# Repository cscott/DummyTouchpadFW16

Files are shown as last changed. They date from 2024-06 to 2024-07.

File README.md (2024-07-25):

# Dummy Touchpad Input Module
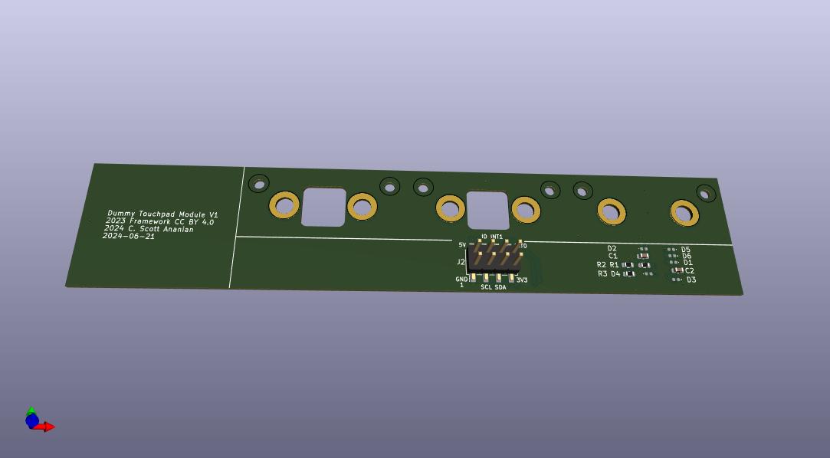
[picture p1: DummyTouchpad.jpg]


This is a dummy touchpad.  All it does is contain the resistors and pads to
tell the FW16 that there is a touchpad installed (though there is not).
It also brings the signal lines out to a 2.54mm SMT header, but that's
mostly for debugging/development, not for any real use.

If you are using this in conjunction with a
[full width touchpad spacer](https://github.com/cscott/TouchpadSpacerFW16)
don't populate the header.

Here's the [schematic](./MinimalSmallInputModule.pdf).

## License
Input Modules © 2023 by Framework Computer Inc is licensed under CC BY 4.0. To view a copy of this license, visit http://creativecommons.org/licenses/by/4.0/

## Fabrication and Assembly
Use a 0.8mm PCB for Input Modules.

As with the Framework [example](https://github.com/FrameworkComputer/InputModules/tree/main/Electrical/MicrocontrollerInputModule) use Keystone 24929
"zero height threaded inserts" ([available from Digikey](https://www.digikey.com/en/products/detail/keystone-electronics/24929/16343672))
where indicated, with the "big" side down.  These are soldered in place
and provide enough steel to engage properly with the magnets on the
FW16 midplate to hold the PCB in place.



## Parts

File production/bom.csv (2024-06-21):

Designator | Footprint | Quantity | Value | LCSC Part #
C1, C2 | 0603 | 2 | 10uF | C96446
H11, H12, H3, H4, H7, H8 | MountingHole_2.1mm | 6 | MountingHole
J1 | PogoPads_2x4_P2.0mm | 1 | Pogo Pins
J2 | PinHeader_2x04_P2.54mm_Vertical_SMD | 1 | Debug Header | C3294462
R1 | 0603 | 1 | 330k | C23137
R2 | 0603 | 1 | 220k | C22961
R3 | 0603 | 1 | 10k | C25804

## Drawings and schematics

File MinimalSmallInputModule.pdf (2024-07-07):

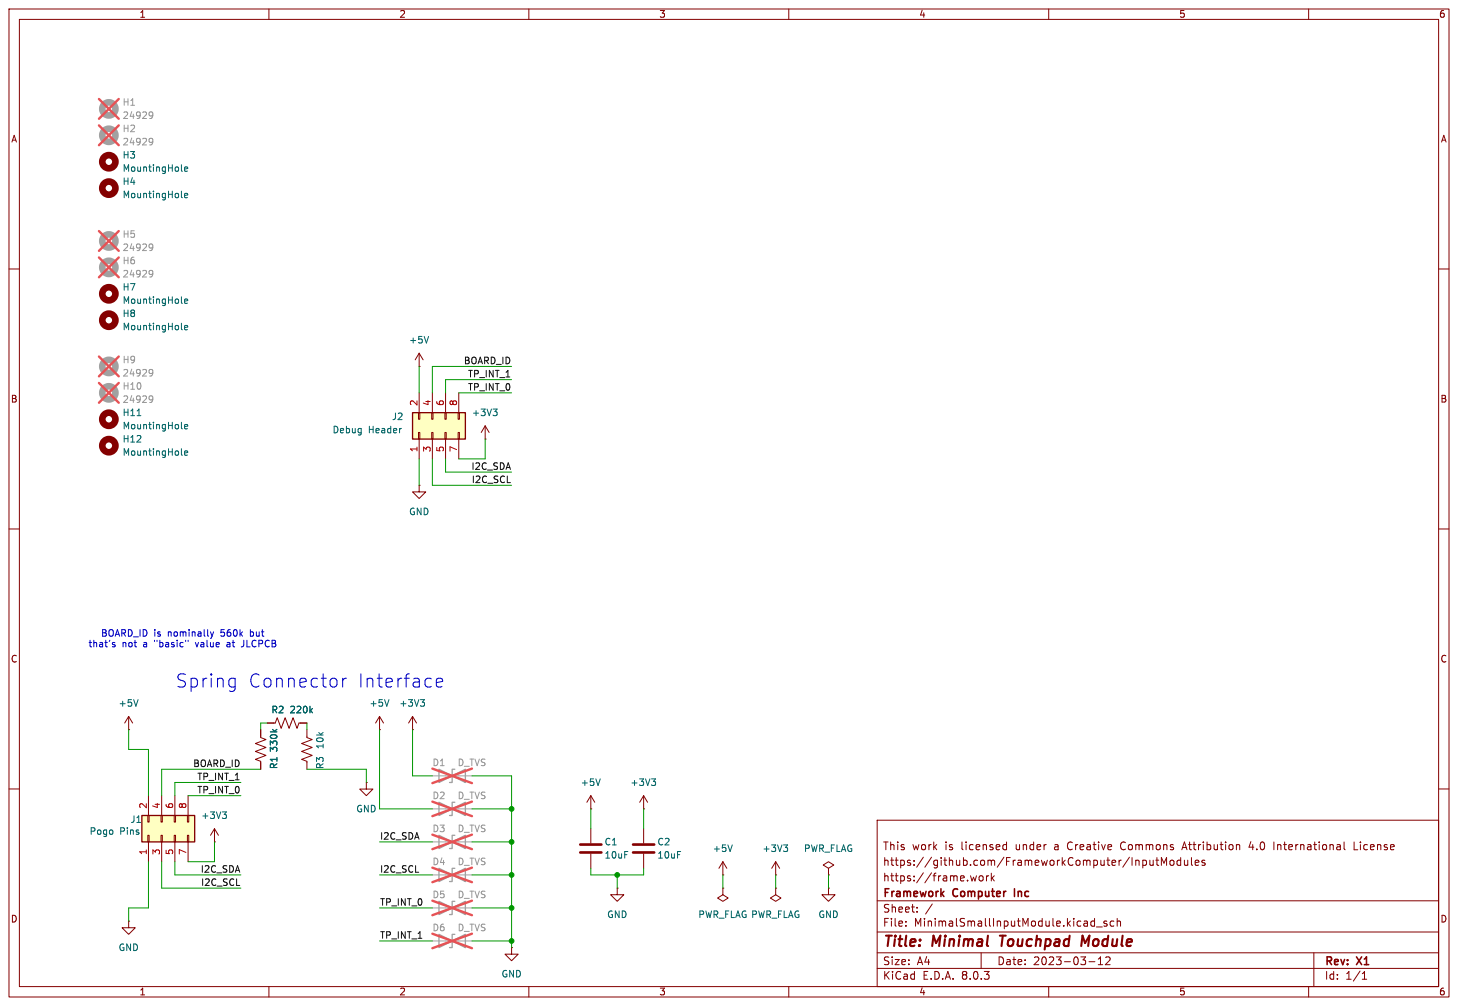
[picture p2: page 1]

Id: 1/1 Title: Minimal Touchpad Module

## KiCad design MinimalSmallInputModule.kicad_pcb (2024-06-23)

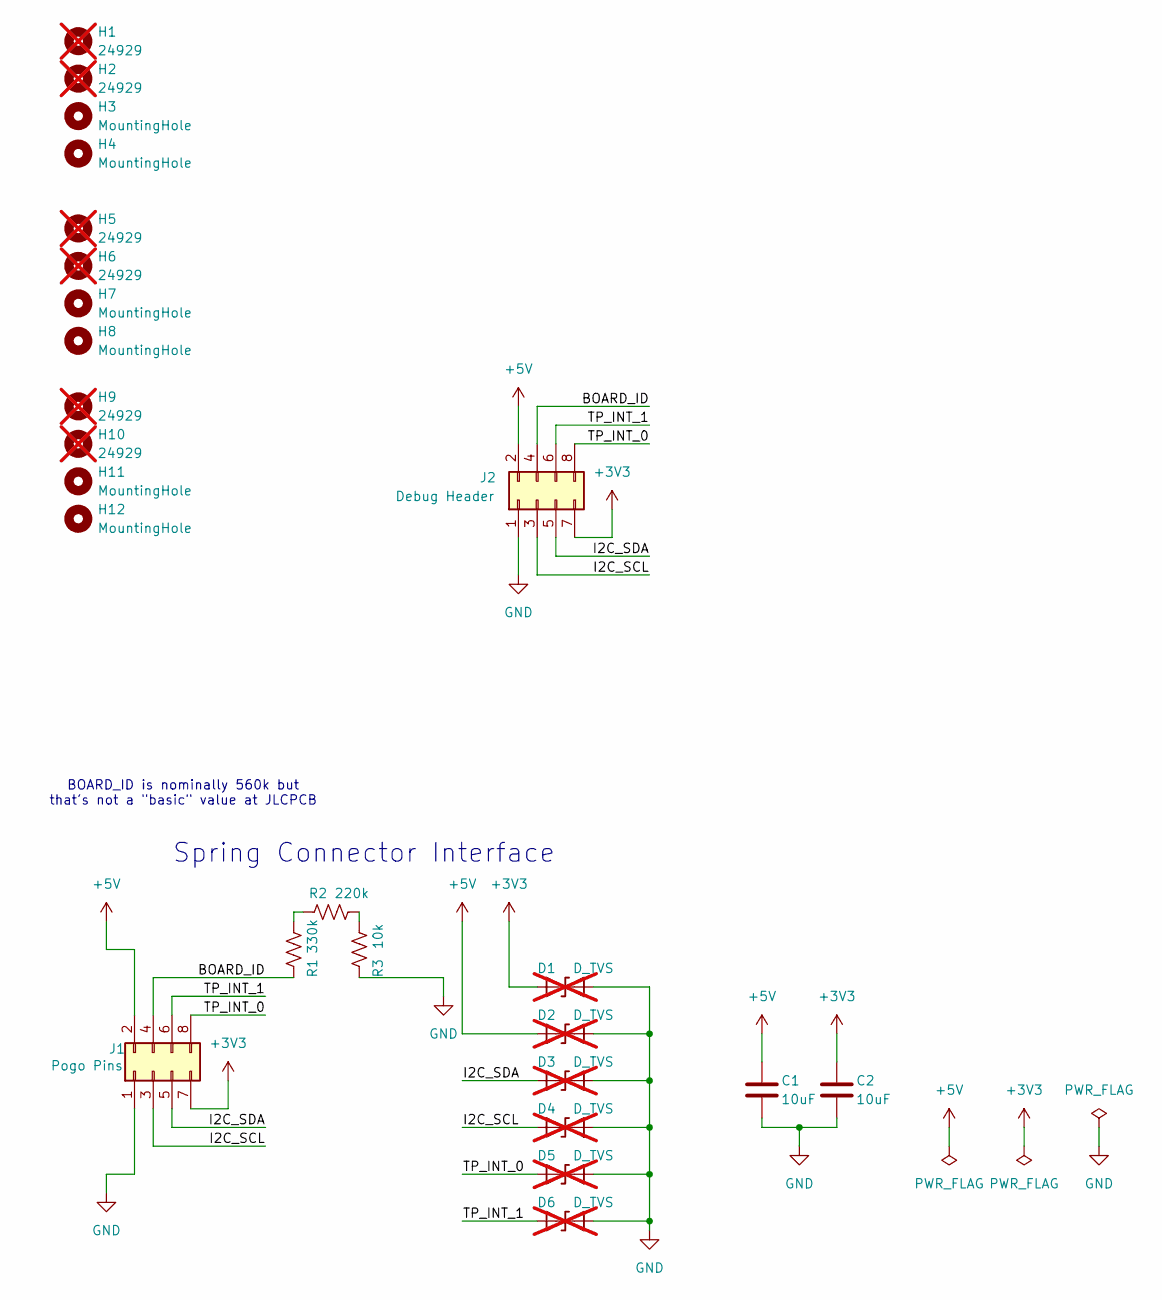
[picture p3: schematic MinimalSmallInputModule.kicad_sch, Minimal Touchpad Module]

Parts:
C1, C2: 10uF; C_0603_1608Metric; Digikey 1276-1869-1-ND
D1, D2, D3, D4, D5, D6: D_TVS; D_0402_1005Metric; Digikey F9744CT-ND; not fitted
H1, H2, H5, H6, H9, H10: 24929; MountingHole_3.7mm_Pad_24929; Digikey 36-24929CT-ND; not fitted
H3, H4, H7, H8, H11, H12: MountingHole; MountingHole_2.1mm
J1: Pogo Pins; PogoPads_2x4_P2.0mm
J2: Debug Header; PinHeader_2x04_P2.54mm_Vertical_SMD; LCSC C3294462
R1: 330k; R_0603_1608Metric; LCSC C23137
R2: 220k; R_0603_1608Metric; LCSC C22961
R3: 10k; R_0603_1608Metric; LCSC C25804

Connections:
+3V3: C2.1, D1.2 (A2), J1.7, J2.7
+5V: C1.1, D2.2 (A2), J1.2, J2.2
/BOARD_ID: J1.4, J2.4, R1.1
/I2C_SCL: D4.2 (A2), J1.3, J2.3
/I2C_SDA: D3.2 (A2), J1.5, J2.5
/TP_INT_0: D5.2 (A2), J1.8, J2.8
/TP_INT_1: D6.2 (A2), J1.6, J2.6
GND: C1.2, C2.2, D1.1 (A1), D2.1 (A1), D3.1 (A1), D4.1 (A1), D5.1 (A1), D6.1 (A1), J1.1, J2.1, R3.1
unnamed: R1.2, R2.2
unnamed: R2.1, R3.2

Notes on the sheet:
BOARD_ID is nominally 560k but that's not a "basic" value at JLCPCB
Spring Connector Interface

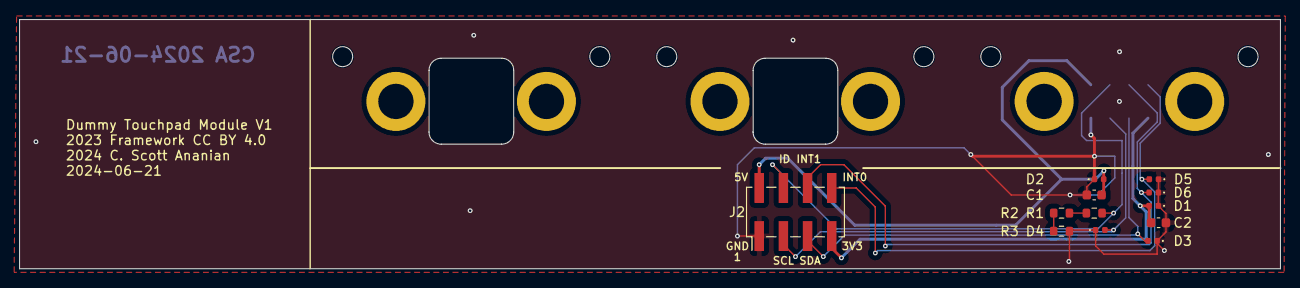
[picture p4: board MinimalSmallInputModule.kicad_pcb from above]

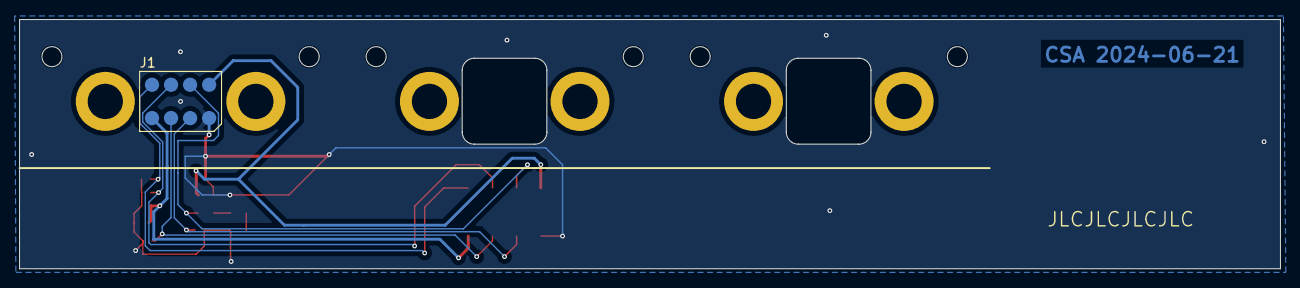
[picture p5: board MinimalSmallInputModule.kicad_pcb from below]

Board: 2 copper layers, 132.4 x 26.2 mm, 25 parts (7 on the bottom side), 10 nets.

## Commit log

2024-06-21 Initial dummy touchpad module, forked from Framework Minimal Input Module
    [MinimalSmallInputModule.kicad_pcb, MinimalSmallInputModule.kicad_sch]
2024-06-21 First complete version sent to JLCPCB
    [MinimalSmallInputModule.kicad_pcb, MinimalSmallInputModule.kicad_sch, bom.csv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]
2024-06-23 Add JLCJLCJLCJLC text (not yet used)
    [MinimalSmallInputModule.kicad_pcb]
2024-07-07 Improve README, add PDF version of schematic

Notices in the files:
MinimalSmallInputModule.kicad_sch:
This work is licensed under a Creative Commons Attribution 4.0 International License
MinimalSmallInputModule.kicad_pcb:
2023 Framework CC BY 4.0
